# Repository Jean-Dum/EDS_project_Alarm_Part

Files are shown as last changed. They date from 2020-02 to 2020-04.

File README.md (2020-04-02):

# EDS_project_Alarm_Project

## Motion detection alarm

## Principal Equipment

	- PIR Sensor               --> EKMC1601111 - Motion sensor 5m 94°, Panasonic
	
	- Electromechanical Buzzer --> kmtg1603 

	- Button (For alarm test)  --> https://www.elfa.se/en/tactile-switch-pts-1no-160gf-6mm-pts645sm43smtr92lfs/p/30119498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

	- Variable resistor (for smoke sensor) --> https://www.elfa.se/en/trimmer-potentiometer-kohm-250-mw-bi-technologies-23br1klftr/p/16432066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
	
	- LoRa module (long range low-power wide-area network technology) --> Murata CMWX1ZZABZ

	- Smoke Sensor --> HS-131 https://www.elfa.se/en/gas-sensor-sencera-co-ltd-hs-131/p/17302706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

### Desired features

The main idea is to build a system which can detect the movement of a person using a PIR sensor. This movement will trigger an alarm and communicate using LoRa to another MCU managed by our associated team. The only way of desactivate the alarm is to introduce the correct code in the second team's terminal.

The system will also include a buzzer and a test button.

### Obtained features

Our PCB is now able to detect the movements up to 4 meters away. It makes the buzzer ring and to stop it you just have to press the button on the PCB.

At the programm beginning there is 10 seconds of waiting in order to wait for the user to go away (otherwise it will disrupt the sensor calibration) during which the info LED is blinking. Then there is 10 seconds of sensor calibration, in which it makes a 40 samples average to make a reference value and makes the LED blinking faster.

Then the programm runs and the buzzer will ring only if the sensor value exceeds the reference value.

If the alarm is stopped by pressing the button, to reactivate it just press again the buttton, the software will again wait 10 seconds to let the user go away to avoid the buzzer to ring immediatly and then run motion detection again. During this time the info LED is blinking again.

Our system send a '1' by serial connection when the sensor is triggered. The alarm can be turned off by serial connection if it receive a '1' but to do so you have to uncomment lines 143 to 152 and build the code again.

#### Here is a diagram of our program:
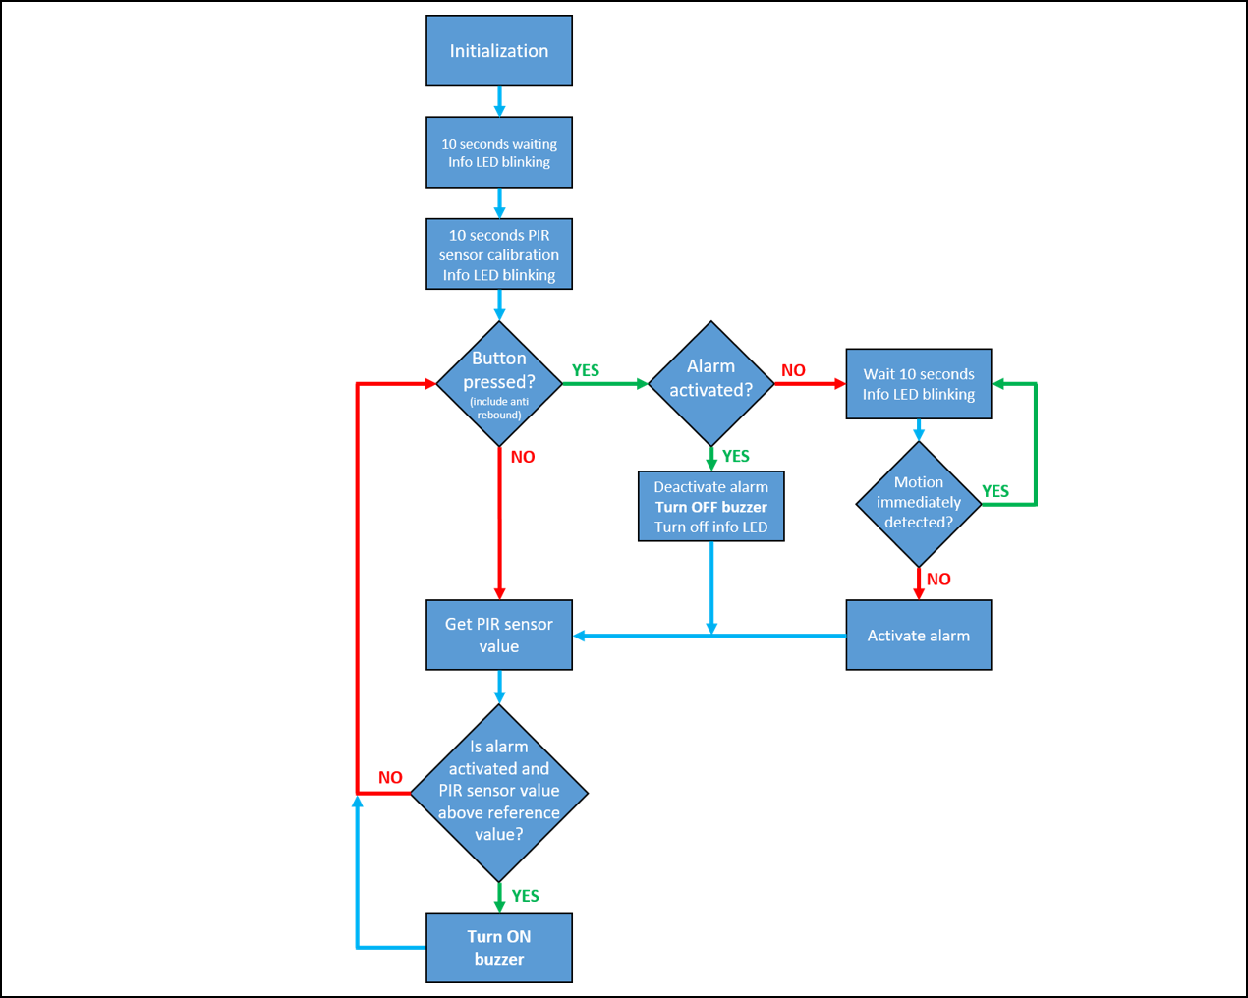
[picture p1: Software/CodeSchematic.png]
Code schematic description


## Run project

### Hardawre

- Connect the St-Link programmer from the nucleo board to the PCB. To do so just connect the SWD pins to the programming pins of our PCB, in the same order.
- Then verify that the nucleo St-Link programmer wont programm the nucleo board but our PCB. To do so remove the St-Link programmer and nucleo board connectors and remove the connector that power the nucleo board.
- Then connect both the St-Link programmer and PCB USB to your computer.

### Software
Open a terminal
#### Packages installation
- First of all install openocd:
> sudo apt-get install openocd
- install cargo:
> sudo apt-get install cargo
- install arm-none-eabi-gdb:
> sudo apt-get install arm-none-eabi-gdb
- Update rust tools:
> rustup update
> rustup target add thumbv7em-none-eabihf

#### Build software
> cargo build --release

#### Run software
- Clone this repo on your computer:
> git clone https://github.com/Jean-Dum/EDS_project_Alarm_Part.git
- Then go in the software directory:
> cd EDS_project_Alarm_Part/Software/
- Execute openocd software:
> openocd -f openocd.cfg
- Open a new terminal (in the same directory) and run the code:
> cargo build --release
- Now you are in the GDB interface, just type "c" and press two times enter key. You can look the code output in the openocd terminal.

## Possible Extras

If everything goes on time and we do not have any big difficulties in the project, we plan to add also some kind of smoke detector so the alarm system is more complete. 

We also thought of adding a fingerprint sensor for desactivating the alarm in the detector terminal.

## Limitations

The fact of working two groups together makes the communication between terminals harder but we dont expect any other big problem in our terminal.

The main limitation was that there few informations about Rust (and especially about the stm32L0) on internet, doing our researchs to resolve our problems was really difficult.

## Design and Electronic

We design our circuit using Kicad and testing some parts of the circuit in LTspice.  

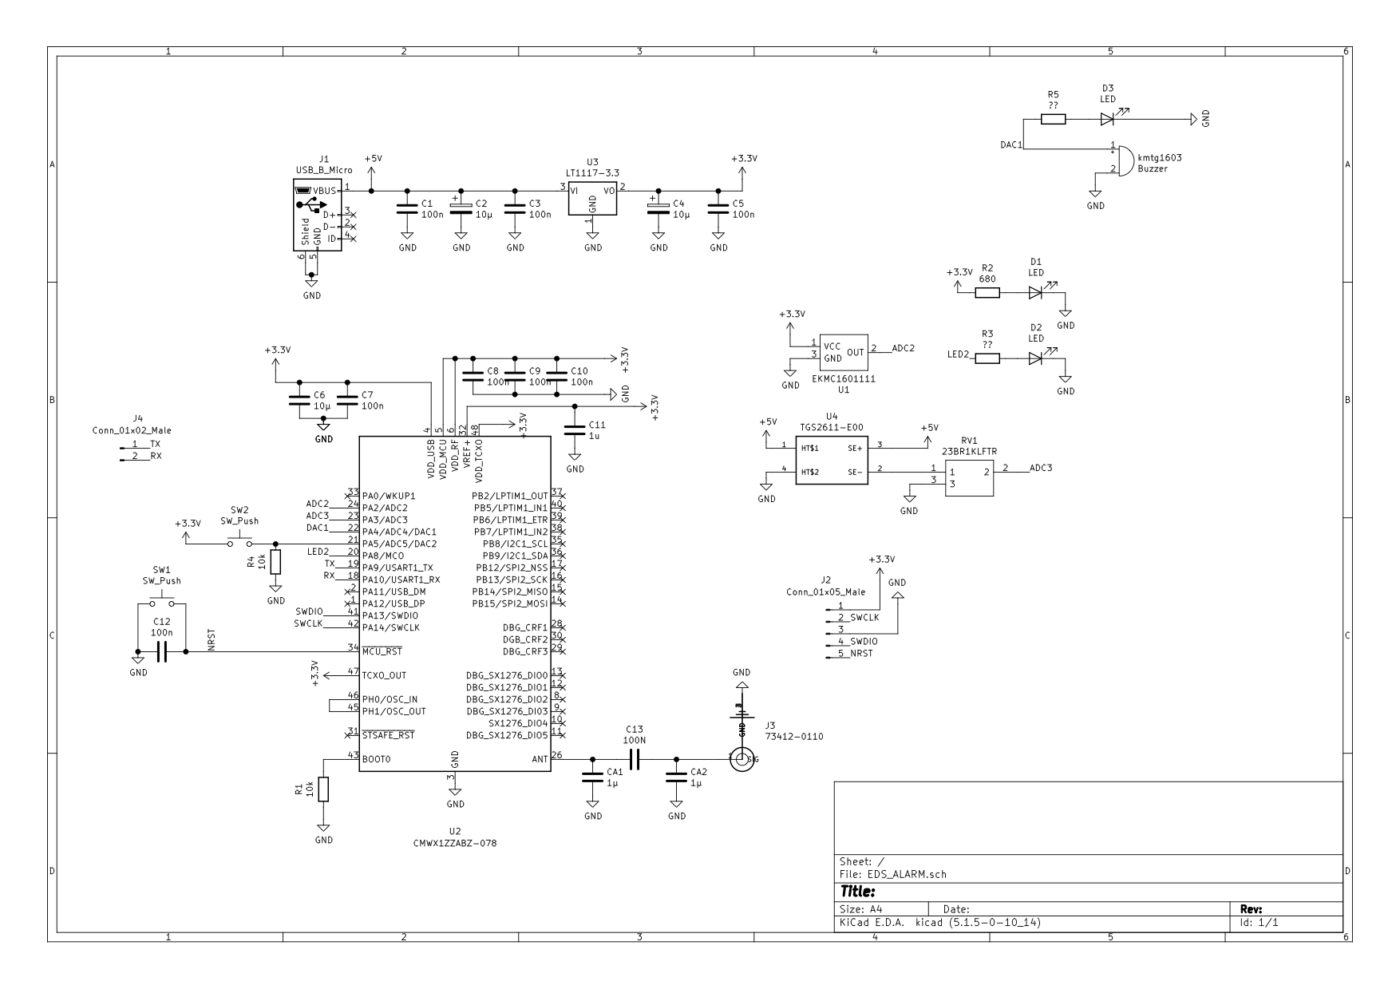
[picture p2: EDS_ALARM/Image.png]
Schematic
   

### Some facts about the circuit
	
- Three different LEDs: one to get infos on the code execution, one for the power and one connected to the buzzer.
	
- We add a different voltage regulator (LT1117) that allows us to have 3.3v always without the need of resistors for adjustment of the output, so we reduces the space used.

- For the Smoke detector we used a potentiometer we can use for changing the output, this is because the detector can work on different environments (humidity, temperature...) and we need to adjust the potentiometer to have an ideal output.

### Layout

For the layout we tried to make the PCB as small as possible so it can fit in a small case and this way the detection system will be more inconspicuous.

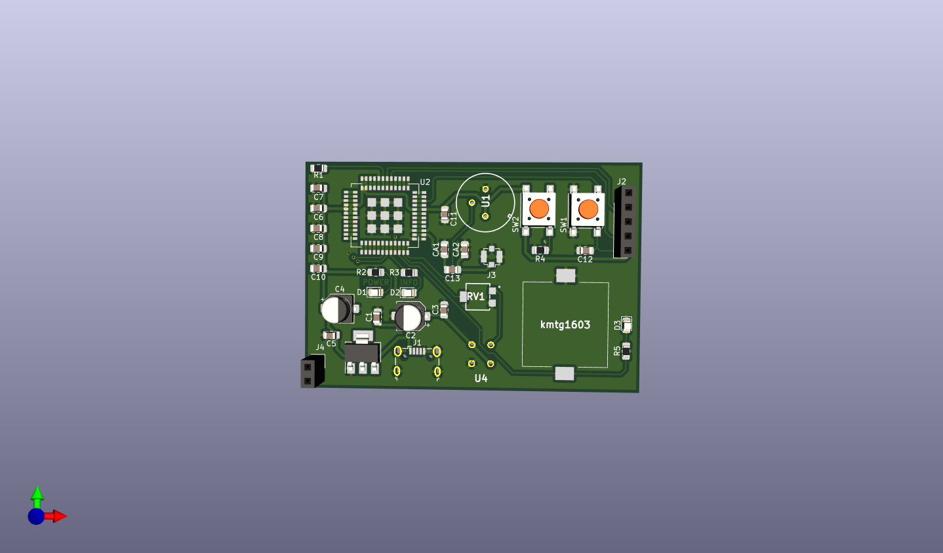
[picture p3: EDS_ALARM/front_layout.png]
Top Layout
   
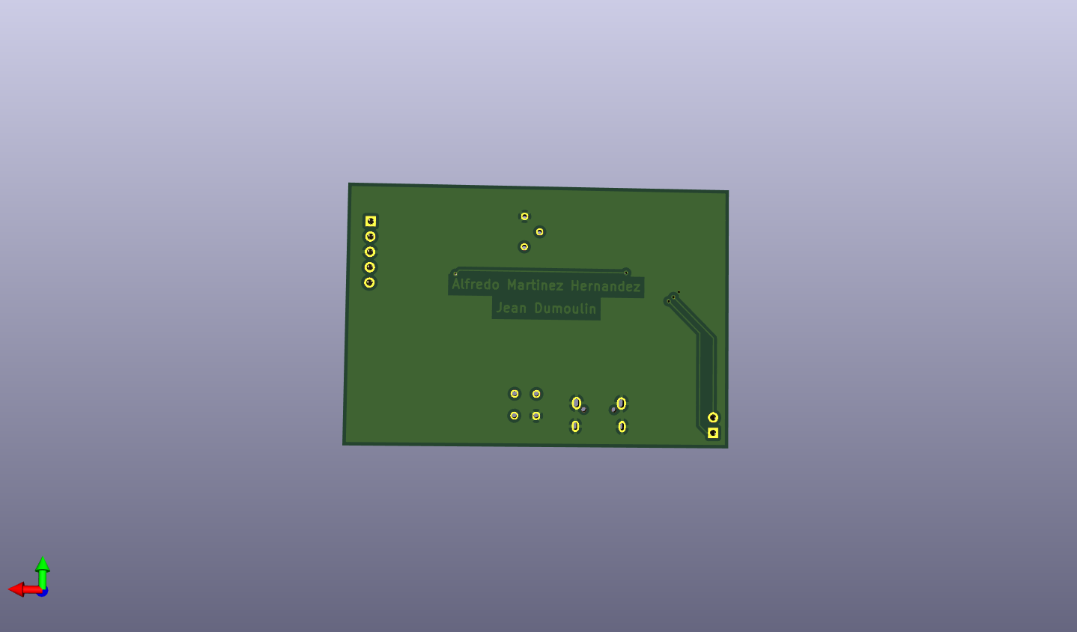
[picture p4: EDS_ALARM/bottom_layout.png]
Bottom Layout
   

All the components are on the same layer (top) but the PIR, this way we have more space and a better 'view' for the motion sensor. The connectors are all placed on the sides of the board so it is easier to use them. We tried to put the buzzer as far as possible from the MCU just incase the vibrations of the buzzer can make any damage on the small soldering pads of the MCU in a large period of time, the decoupling capacitors and sensors are placed as close as possible from the MCU.

### Testing

We did some different tests on the board before and after ordering it
- We used LTspice to make sure everything was okey
- Test for short-circuits and bad connections
- Test after soldering the MCU
- For short-circuits between pads (here we detected a problem)
- For voltage reverse to make sure all the pads were connected
- We tested the MCU by connecting it at a low current
- Test the final performance 

## Issues / Problems 

- Circuit
	- The LT1117 pins of the footprint where wrong (they were saved as if it was LM1117) so we had to make a small fix

- Layout and soldering
	- We had to apply the re-flow process twice because of a lack of flux in the first re-flow but finally applying more flux and doing the process again we managed to solder it perfect.

- Programming
	- It took us some time to manage to connect the PCB and didn't succeed to use vscode to run our code.
	- We made a mistake on the pins connection: The PA4 pin (used for the buzzer) don't generate PWM, we had to add a wire between the PA4 and PA3 pins because PA3 can generate PWM and is used for the smoke sensor, which is not used.
	- We didn't succeed to use the Lora module, by lack of time and because this one is way to complicated to use.
	- All the programming part was really complicated to realise, in fact there is not a lot of things about rust and espetially with the stm32L0 on internet, resolving our issues was a real struggle.

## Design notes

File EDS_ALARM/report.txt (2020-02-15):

Se ha creado el archivo de trazado "/Users/alfredomartinezhernandez/Documents/GitHub/PROJECTS/EDS_project_Alarm_Part/EDS_ALARM/EDS_ALARM-F_Cu.gbr".
Se ha creado el archivo de trazado "/Users/alfredomartinezhernandez/Documents/GitHub/PROJECTS/EDS_project_Alarm_Part/EDS_ALARM/EDS_ALARM-B_Cu.gbr".
Se ha creado el archivo de trazado "/Users/alfredomartinezhernandez/Documents/GitHub/PROJECTS/EDS_project_Alarm_Part/EDS_ALARM/EDS_ALARM-F_Adhes.gbr".
Se ha creado el archivo de trazado "/Users/alfredomartinezhernandez/Documents/GitHub/PROJECTS/EDS_project_Alarm_Part/EDS_ALARM/EDS_ALARM-B_Adhes.gbr".
Se ha creado el archivo de trazado "/Users/alfredomartinezhernandez/Documents/GitHub/PROJECTS/EDS_project_Alarm_Part/EDS_ALARM/EDS_ALARM-F_Paste.gbr".
Se ha creado el archivo de trazado "/Users/alfredomartinezhernandez/Documents/GitHub/PROJECTS/EDS_project_Alarm_Part/EDS_ALARM/EDS_ALARM-B_Paste.gbr".
Se ha creado el archivo de trazado "/Users/alfredomartinezhernandez/Documents/GitHub/PROJECTS/EDS_project_Alarm_Part/EDS_ALARM/EDS_ALARM-F_SilkS.gbr".
Se ha creado el archivo de trazado "/Users/alfredomartinezhernandez/Documents/GitHub/PROJECTS/EDS_project_Alarm_Part/EDS_ALARM/EDS_ALARM-B_SilkS.gbr".
Se ha creado el archivo de trazado "/Users/alfredomartinezhernandez/Documents/GitHub/PROJECTS/EDS_project_Alarm_Part/EDS_ALARM/EDS_ALARM-F_Mask.gbr".
Se ha creado el archivo de trazado "/Users/alfredomartinezhernandez/Documents/GitHub/PROJECTS/EDS_project_Alarm_Part/EDS_ALARM/EDS_ALARM-B_Mask.gbr".
Se ha creado el archivo de trazado "/Users/alfredomartinezhernandez/Documents/GitHub/PROJECTS/EDS_project_Alarm_Part/EDS_ALARM/EDS_ALARM-Edge_Cuts.gbr".
Se ha creado el archivo de trazado "/Users/alfredomartinezhernandez/Documents/GitHub/PROJECTS/EDS_project_Alarm_Part/EDS_ALARM/EDS_ALARM-Margin.gbr".
Se ha creado el archivo de trazado "/Users/alfredomartinezhernandez/Documents/GitHub/PROJECTS/EDS_project_Alarm_Part/EDS_ALARM/EDS_ALARM-F_CrtYd.gbr".
Se ha creado el archivo de trazado "/Users/alfredomartinezhernandez/Documents/GitHub/PROJECTS/EDS_project_Alarm_Part/EDS_ALARM/EDS_ALARM-B_CrtYd.gbr".
Se ha creado el archivo de trazado "/Users/alfredomartinezhernandez/Documents/GitHub/PROJECTS/EDS_project_Alarm_Part/EDS_ALARM/EDS_ALARM-F_Fab.gbr".
Se ha creado el archivo de trazado "/Users/alfredomartinezhernandez/Documents/GitHub/PROJECTS/EDS_project_Alarm_Part/EDS_ALARM/EDS_ALARM-B_Fab.gbr".

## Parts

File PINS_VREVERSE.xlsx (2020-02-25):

pin Nº | DESCRIPTION | V(reverse)
1 | X | 0.702
2 | X | 0.697
3 | GND | 0.001
4 | VDD_USB | 0.948
5 | VDD_MCU | 0.948
6 | VDD_RF | 0.948
7 | GND | 0.001
8 | X | 1383
9 | X | 0.986
10 | X | 1383
11 | X | 1384
12 | X | 1386
13 | X | 0.680
14 | X | 0.741
15 | X | 0.711
16 | X | 0.710
17 | X | 0.734
18 | RX | 0.706
19 | TX | 0.711
20 | LED2 | 0.714
21 | PA5(SWITCH) | 0.686
22 | DAC1(BUZZER) | 0.687
23 | ADC3(SMOKE) | 0.720
24 | ADC2 (PIR) | 0.721
25 | GND | 0.001
26 | ANTENA | ??
27 | GND | 0.001
28 | X | 0.721
29 | X | 0.707
30 | X | 0.707
31 | X | ??
32 | VREF+ | 0.403
33 | X | 0.720
34 | NRST | 0.739
35 | X | 0.713
36 | X | 0.716
37 | X | ??
38 | X | ??
39 | X | ??
40 | X | ??
41 | SWDIO | 0.739
42 | SWCLK | 0.739
43 | BOOT0 | 0.731
44 | GND | 0.001
45 | OSC_OUT | 0.691
46 | OSC_IN | 0.690
47 | TCXO_OUT | 0.403
48 | VDD_TCX0 | 0.403
49 | GND
50 | GND
51 | GND
52 | GND
53 | GND
54 | GND
55 | GND
56 | GND
57 | GND

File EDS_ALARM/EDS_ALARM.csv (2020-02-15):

Id | Identificador | Empaquetado | Cantidad | Identificación | Suministrador y ref
1 | R2 | R_0805_2012Metric_Pad1.15x1.40mm_HandSolder | 1 | 680 |  | x
2 | U2 | CMWX1ZZABZ_NEW | 1 | CMWX1ZZABZ-078
3 | C1,C3,C5,C7,C8,C9,C10,C12 | C_0805_2012Metric_Pad1.15x1.40mm_HandSolder | 8 | 100n |  | x
4 | C2,C4 | CP_Elec_5x4.4 | 2 | 10µ |  | x
5 | C6 | C_0805_2012Metric_Pad1.15x1.40mm_HandSolder | 1 | 10µ |  | x
6 | C11 | C_0805_2012Metric_Pad1.15x1.40mm_HandSolder | 1 | 1u |  | x
7 | C13 | C_0805_2012Metric_Pad1.15x1.40mm_HandSolder | 1 | 100N |  | x
8 | CA1,CA2 | C_0805_2012Metric_Pad1.15x1.40mm_HandSolder | 2 | 1µ |  | x
9 | J1 | USB_Mini-B_Lumberg_2486_01_Horizontal CHANGED!! | 1 | USB_B_Micro |  | X
10 | J3 | U.FL_Molex_MCRF_73412-0110_Vertical | 1 | 73412-0110 |  | X
11 | R1,R4 | R_0805_2012Metric_Pad1.15x1.40mm_HandSolder | 2 | 10k |  | X
12 | U3 | SOT-223 | 1 | LT1117-3.3 |  | X
13 | U1 | VZ-STANDARD | 1 | EKMC1601111 |  | X
14 | D1,D2,D3 | LED_0805_2012Metric | 3 | LED |  | X
15 | RV1 | 23B_1 | 1 | 23BR1KLFTR |  | X
16 | SW1,SW2 | SW_SPST_PTS645 | 2 | SW_Push |  | X
17 | kmtg1603 | KMTG16031 | 1 | Buzzer |  | X
18 | U4 | TGS2611C00 | 1 | TGS2611-E00 |  | X
19 | J2 | PinSocket_1x05_P2.54mm_Vertical | 1 | Conn_01x05_Male |  | x
20 | J4 | PinSocket_1x02_P2.54mm_Vertical | 1 | Conn_01x02_Male |  | X
21 | R3,R5 | R_0805_2012Metric_Pad1.15x1.40mm_HandSolder | 2 | ?? |  | x

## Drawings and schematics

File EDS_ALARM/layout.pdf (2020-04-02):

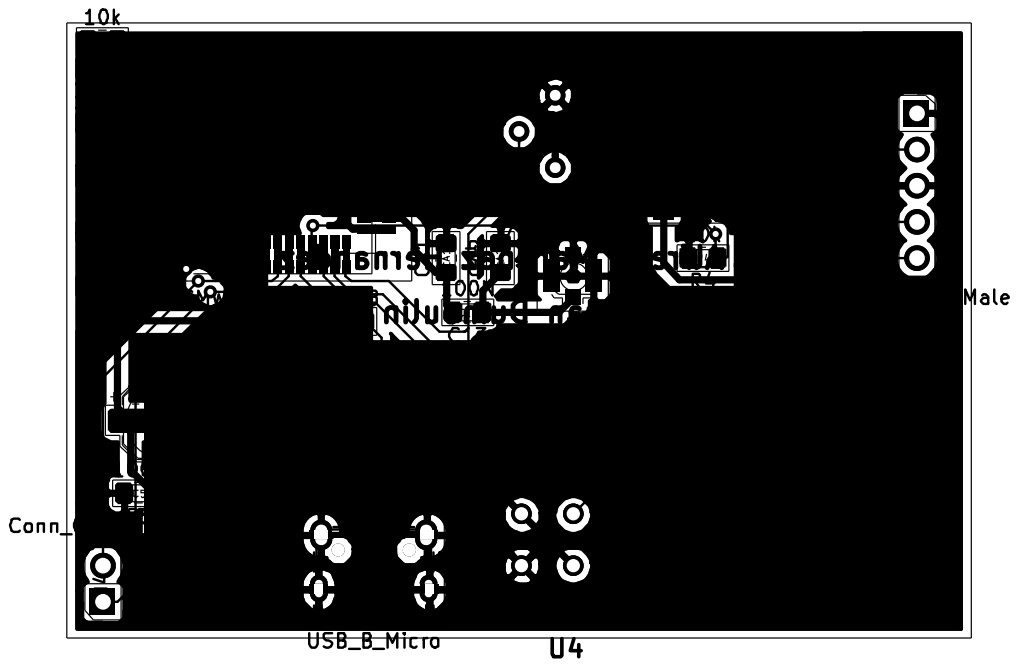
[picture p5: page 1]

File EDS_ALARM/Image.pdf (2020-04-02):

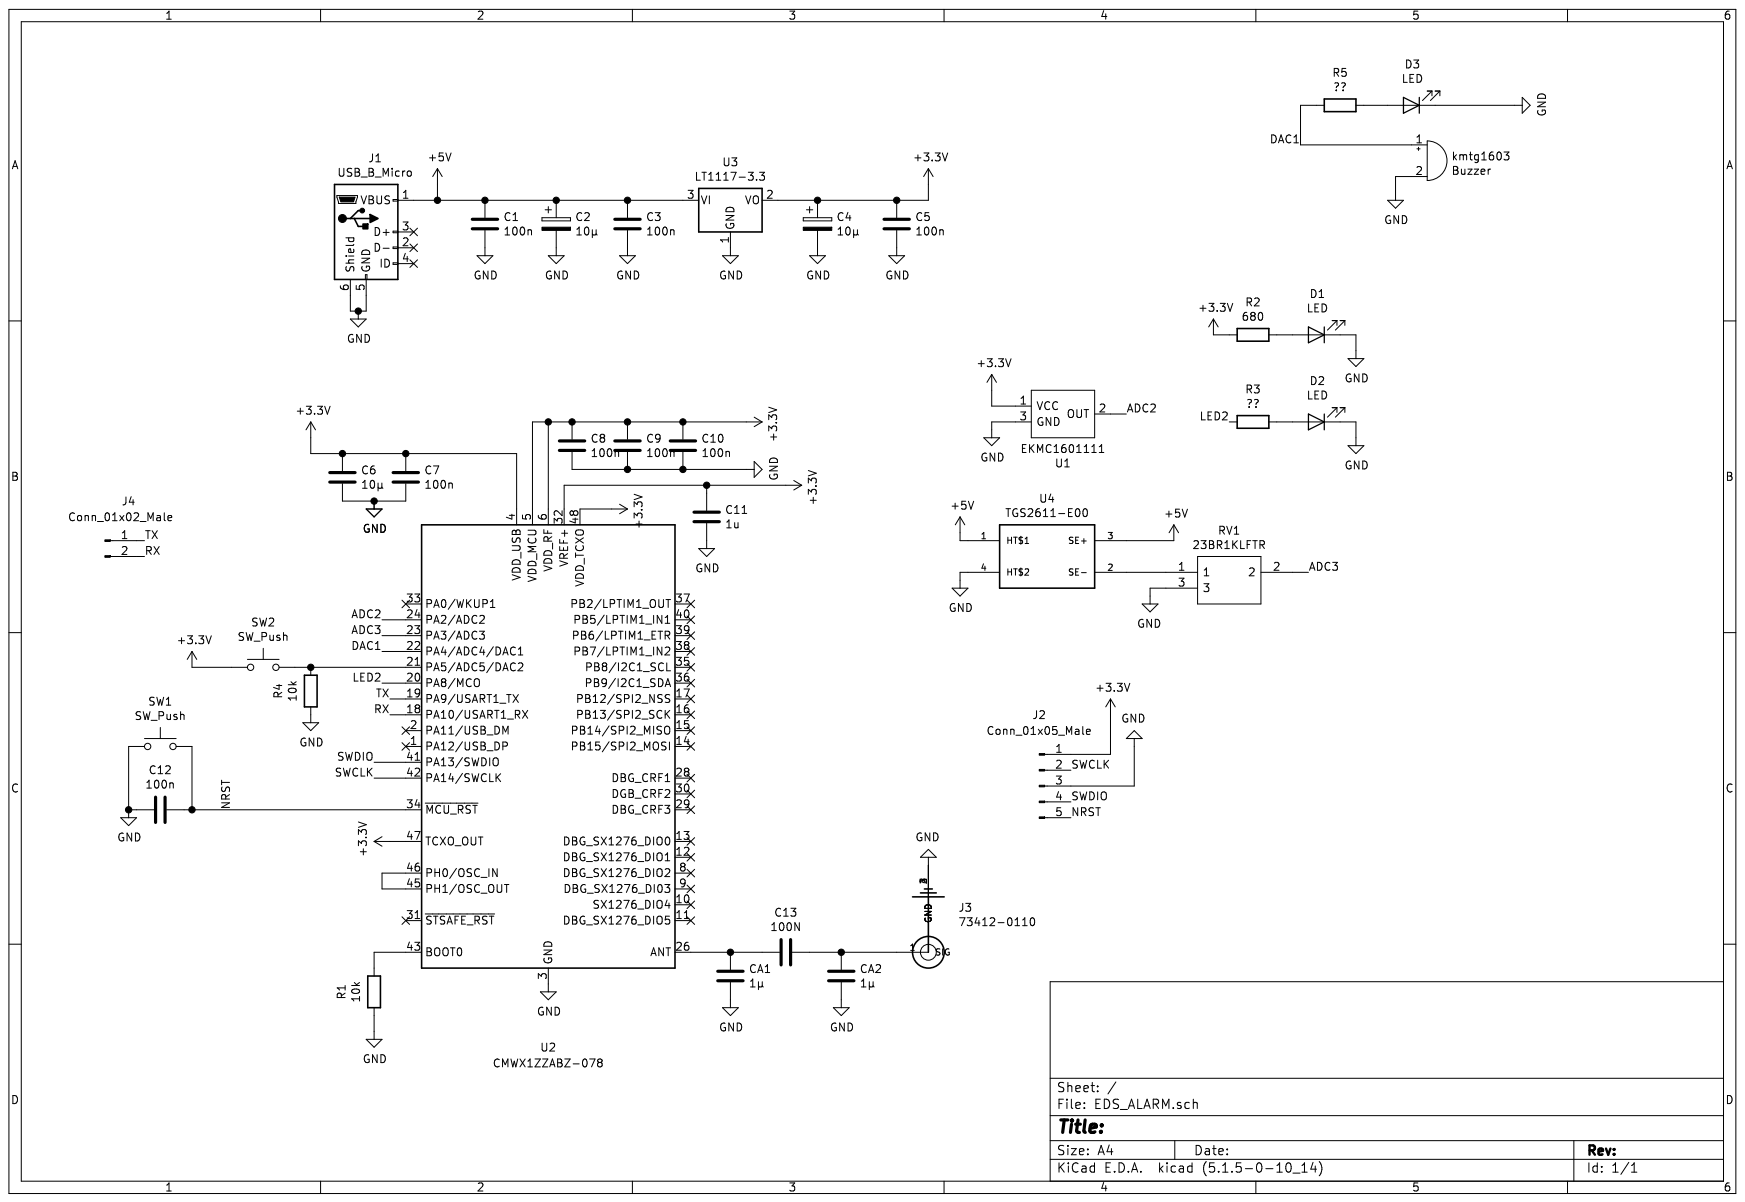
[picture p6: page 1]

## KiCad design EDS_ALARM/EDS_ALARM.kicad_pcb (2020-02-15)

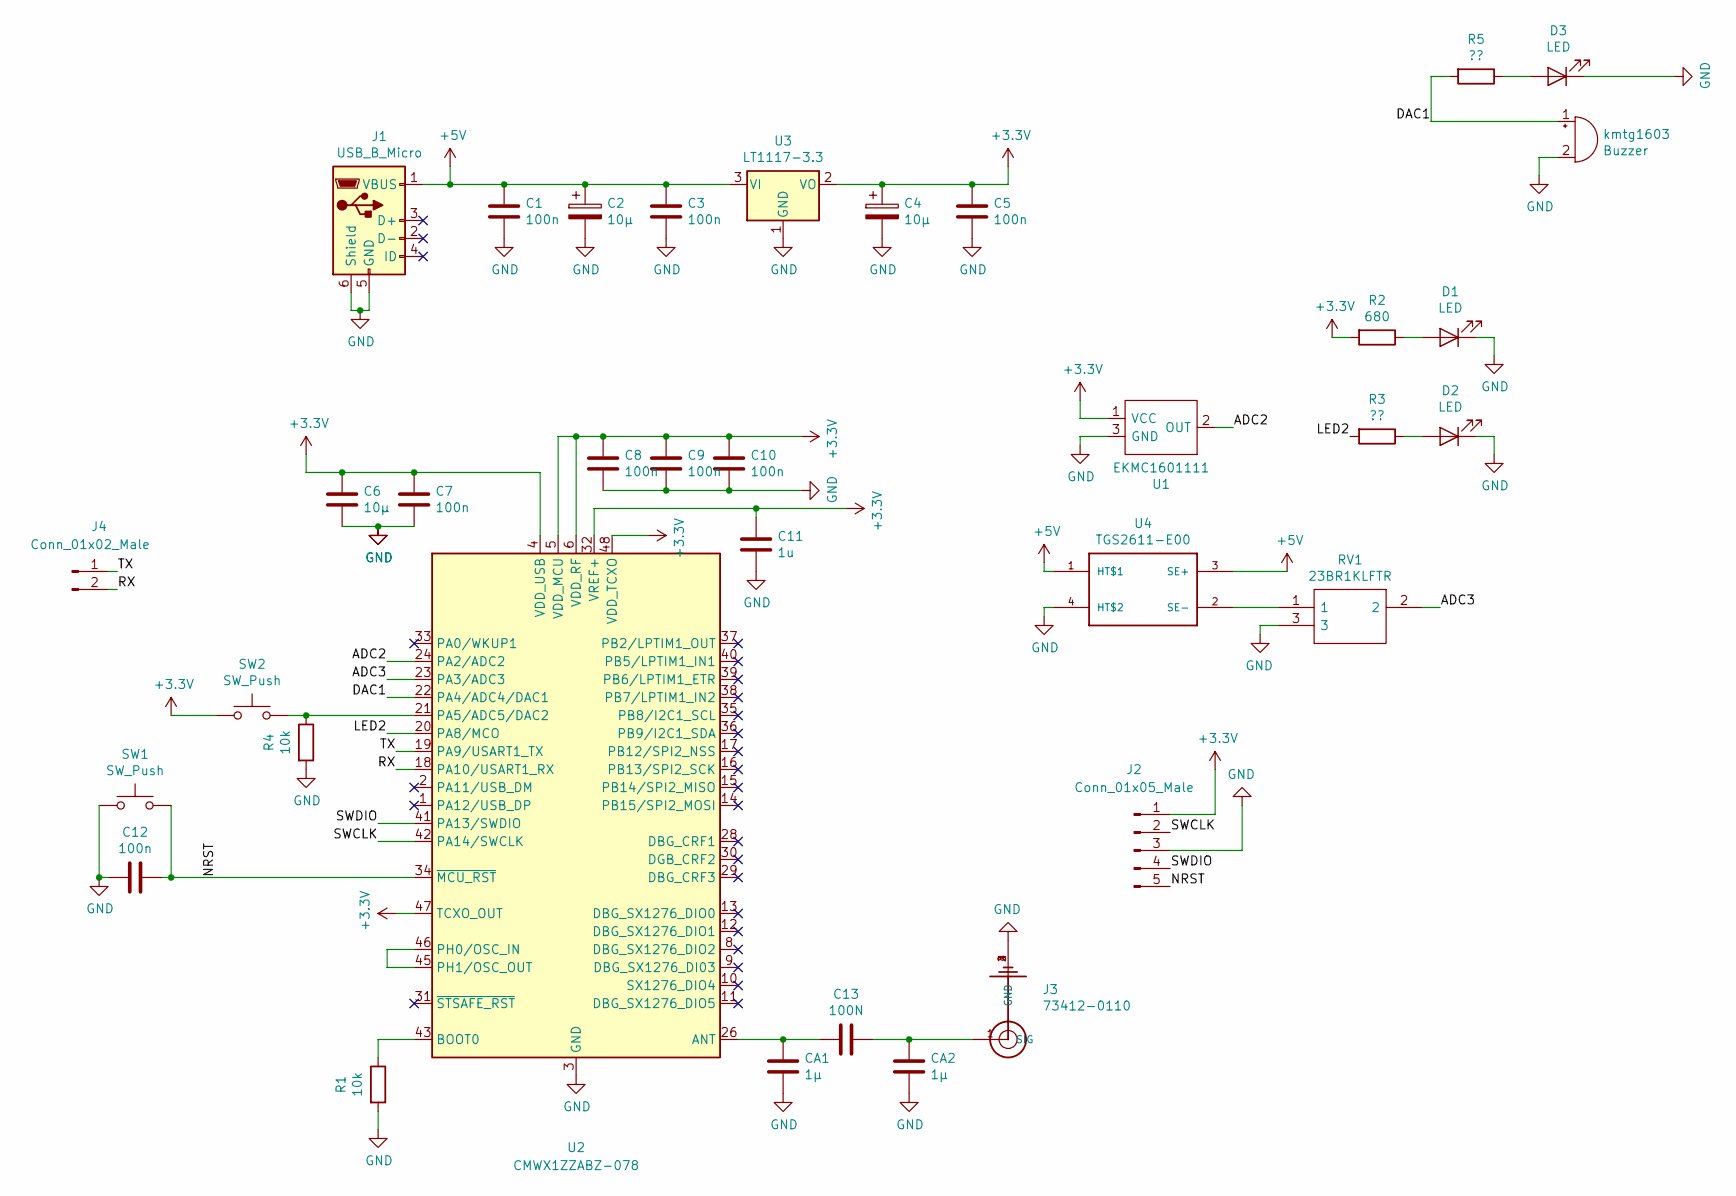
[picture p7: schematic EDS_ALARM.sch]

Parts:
C1, C3, C5, C7, C8, C9, C10, C12: 100n; C_0805_2012Metric_Pad1.15x1.40mm_HandSolder
C2, C4: 10µ; CP_Elec_5x4.4
C6: 10µ; C_0805_2012Metric_Pad1.15x1.40mm_HandSolder
C11: 1u; C_0805_2012Metric_Pad1.15x1.40mm_HandSolder
C13: 100N; C_0805_2012Metric_Pad1.15x1.40mm_HandSolder
CA1, CA2: 1µ; C_0805_2012Metric_Pad1.15x1.40mm_HandSolder
D1, D2, D3: LED; LED_0805_2012Metric
J1: USB_B_Micro; USB_Micro-B_Wuerth_629105150521
J2: Conn_01x05_Male; PinSocket_1x05_P2.54mm_Vertical
J3: 73412-0110; U.FL_Molex_MCRF_73412-0110_Vertical
J4: Conn_01x02_Male; PinSocket_1x02_P2.54mm_Vertical
R1, R4: 10k; R_0805_2012Metric_Pad1.15x1.40mm_HandSolder
R2: 680; R_0805_2012Metric_Pad1.15x1.40mm_HandSolder
R3, R5: ??; R_0805_2012Metric_Pad1.15x1.40mm_HandSolder
RV1: 23BR1KLFTR; 23B_1; Manufacturer_Part_Number 23BR1KLFTR; Mouser Part Number 858-23BR1KLFTR
SW1, SW2: SW_Push; SW_SPST_PTS645
U1: EKMC1601111; VZ-STANDARD; Manufacturer_Part_Number EKMC1601111; Mouser Part Number 769-EKMC1601111
U2: CMWX1ZZABZ-078; CMWX1ZZABZ_NEW
U3: LT1117-3.3; SOT-223
U4: TGS2611-E00; TGS2611C00
kmtg1603: Buzzer; KMTG16031

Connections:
+3V3: C4.1, C5.1, C6.1, C7.1, C8.1, C9.1, C10.1, C11.1, J2.1, R2.2, SW2.1, U1.1 (VCC), U2.4 (VDD_USB), U2.5 (VDD_MCU), U2.6 (VDD_RF), U2.32 (VREF+), U2.47 (TCXO_OUT), U2.48 (VDD_TCXO), U3.2 (VO)
+5V: C1.1, C2.1, C3.1, J1.1 (VBUS), U3.3 (VI), U4.1 (HT$1), U4.3 (SE+)
/ADC2: U1.2 (OUT), U2.24 (PA2/ADC2)
/ADC3: RV1.2, U2.23 (PA3/ADC3)
/DAC1: R5.2, U2.22 (PA4/ADC4/DAC1), kmtg1603.1 (-)
/LED2: R3.2, U2.20 (PA8/MCO)
/NRST: C12.1, J2.5, SW1.2, U2.34 (~MCU_RST)
/RX: J4.2, U2.18 (PA10/USART1_RX)
/SWCLK: J2.2, U2.42 (PA14/SWCLK)
/SWDIO: J2.4, U2.41 (PA13/SWDIO)
/TX: J4.1, U2.19 (PA9/USART1_TX)
GND: C1.2, C2.2, C3.2, C4.2, C5.2, C6.2, C7.2, C8.2, C9.2, C10.2, C11.2, C12.2, CA1.2, CA2.2, D1.1 (K), D2.1 (K), D3.1 (K), J1.5 (GND), J1.6 (Shield), J2.3, J3.2 (GND), J3.3 (GND), J3.4 (GND), R1.2, R4.2, RV1.3, SW1.1, U1.3 (GND), U2.3 (GND), U2.7 (GND), U2.25 (GND), U2.27 (GND), U2.44 (GND), U2.49 (GND), U2.50 (GND), U2.51 (GND), U2.52 (GND), U2.53 (GND), U2.54 (GND), U2.55 (GND), U2.56 (GND), U2.57 (GND), U3.1 (GND), U4.4 (HT$2), kmtg1603.2 (+)
unnamed: C13.1, CA2.1, J3.1 (SIG)
unnamed: C13.2, CA1.1, U2.26 (ANT)
unnamed: D1.2 (A), R2.1
unnamed: D2.2 (A), R3.1
unnamed: D3.2 (A), R5.1
unnamed: R1.1, U2.43 (BOOT0)
unnamed: R4.1, SW2.2, U2.21 (PA5/ADC5/DAC2)
unnamed: RV1.1, U4.2 (SE-)
unnamed: U2.45 (PH1/OSC_OUT), U2.46 (PH0/OSC_IN)

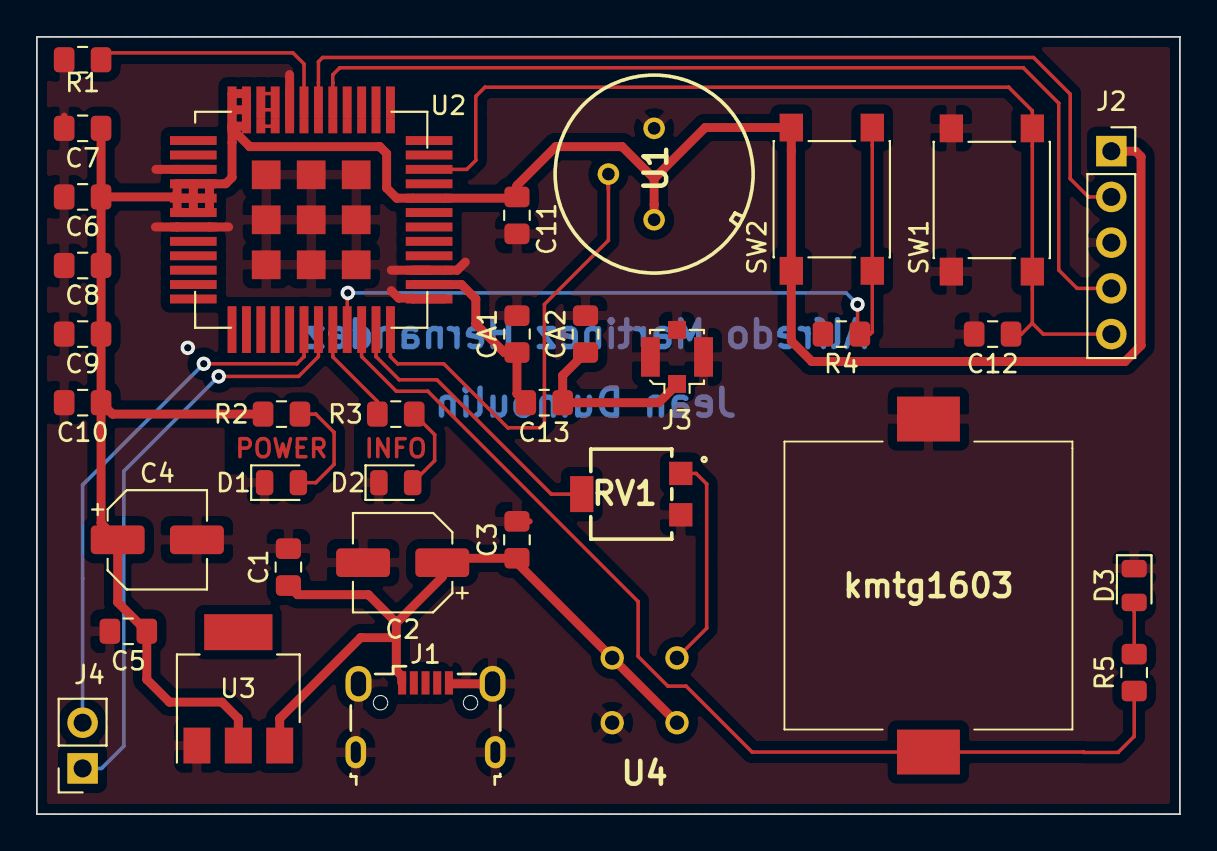
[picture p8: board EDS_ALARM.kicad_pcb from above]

Board: 2 copper layers, 63.5 x 43.2 mm, 35 parts (0 on the bottom side), 21 nets.

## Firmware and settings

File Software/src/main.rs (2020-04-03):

// Made by Jean Dumoulin and Alfredo Martinez Hernandez
// This code is meant to ring the alarm when the PIR sensor detects movement next to it

#![no_main]
#![no_std]
#![allow(non_snake_case)] 
#![deny(unsafe_code)]
#![deny(warnings)]

extern crate panic_halt;

use cortex_m_rt::entry;
use cortex_m_semihosting::{hprintln, hprint};
use stm32l0xx_hal::{self, pac, pwm, prelude::*, rcc::Config, serial};
// use nb::block; Uncomment if serial input is used

extern crate cortex_m;

#[entry]
fn main() -> ! {
    hprintln!("\nBeginning initialization").unwrap();

    let dp = pac::Peripherals::take().unwrap();
    let cp = cortex_m::Peripherals::take().unwrap();

    // Configure the clock.
    let mut rcc = dp.RCC.freeze(Config::hsi16());

    // Get the delay provider.
    let mut delay = cp.SYST.delay(rcc.clocks);

    // Acquire the GPIOA peripheral. This also enables the clock for GPIOA in the RCC register.
    let gpioa = dp.GPIOA.split(&mut rcc);

    // Configure PA8 as output (info LED output)
    let mut infoLED = gpioa.pa8.into_push_pull_output();

    // Configure PA5 as input (SW2)
    let button = gpioa.pa5.into_push_pull_output();
    
    // Configure the timer as PWM on PA3 (connected to PA4)
    let pwm = pwm::Timer::new(dp.TIM2, 1.khz(), &mut rcc);
    let mut pwm = pwm.channel4.assign(gpioa.pa3);
    let max_duty = pwm.get_max_duty() / 4095;
    pwm.enable();
    
    // Configure ADC on PA2
    let mut adc = dp.ADC.constrain(&mut rcc);
    let mut a2 = gpioa.pa2.into_analog();

    // Configure the serial peripheral on pa9 and pa10
    let tx_pin = gpioa.pa9;
    let rx_pin = gpioa.pa10;
    let serial = dp
        .USART1
        .usart((tx_pin, rx_pin), serial::Config::default(), &mut rcc)
        .unwrap();
    let (mut tx, _rx) = serial.split();

    // Initialize PIR reference value to 0
    let mut PIR_ref:u16 = 0;

    // Initialize the alarm activation boolean
    let mut alarmOnOff = true;

    // 5 seconds pause, indicates to the user that he must move away to avoid an immediate ringing
    for x in 0..10 {
        hprint!("\rWait {}s", 4 - x/2).unwrap();
        // Blink the info LED: 250ms OFF, 250ms ON
        delay.delay(250.ms());
        infoLED.set_low().unwrap();
        delay.delay(250.ms());
        infoLED.set_high().unwrap();
    }
    // Print new line
    hprintln!("").unwrap();
    // 5 seconds initialization time, makes the sum of 20 samples
    for x in 0..20 {
        hprint!("\rCalibration: {}s", 4 - x/4).unwrap();
        // Sum a PIR ADC sample
        PIR_ref = PIR_ref.wrapping_add(adc.read(&mut a2).unwrap());
        // Blink the info LED: 125ms OFF, 125ms ON
        delay.delay(125.ms());
        infoLED.set_low().unwrap();
        delay.delay(125.ms());
        infoLED.set_high().unwrap();
    }

    // Divide the result of the sum by 20, the result of the average is doubled
    let PIR_ref: u16 = PIR_ref/10;
    // Prints the average result
    hprintln!("\nReference value: {}\n", PIR_ref).unwrap();

    loop {
        // If the button is pushed
        if button.is_high().unwrap(){
            // Wait until the button is released
            while button.is_high().unwrap(){ 
                // Wait 200ms to avoid rebounce
                delay.delay(200.ms());
            }
            // Invert the alarm switch
            alarmOnOff = !alarmOnOff;
            // If the alarm is activated
            if alarmOnOff == true{
                hprintln!("\nAlarm activated").unwrap();
                // 5 seconds pause, indicates to the user that he must move away, if not it continues
                let mut temp: u8 = 0;
                loop {
                    hprint!("\rWait {}s", 9 - temp/2).unwrap();
                    // Incremet of 500ms
                    temp += 1;
                    // Blink the info LED: 250ms OFF, 250ms ON
                    delay.delay(250.ms());
                    infoLED.set_low().unwrap();
                    delay.delay(250.ms());
                    infoLED.set_high().unwrap();
                    // Take a PIR ADC sample
                    let val: u16 = adc.read(&mut a2).unwrap();
                    // If 10 seconds passed and the PIR value is less than the reference, quit the loop
                    if temp >= 20 && val < PIR_ref  {
                        break();
                    }
                    // If 10 seconds passed and the PIR value is higher than the reference, wait 5 more seconds
                    else if temp >= 20{
                        temp = 0;
                    }
                }
                hprint!("\n").unwrap();
            }
            // If the alarm is desactivated
            else {
                tx.write(0).unwrap();
                hprintln!("\nAlarm desactivated").unwrap();
                // Turn OFF the info LED
                infoLED.set_low().unwrap();
                // Set the PWM duty cycle to 0
                pwm.set_duty(max_duty * 0);
            }
        }

        // Part of the code which allows to desactivate the alarm if a '1' is received on serial port
        /*
        if block!(rx.read()).unwrap() == 1 {
            tx.write(0).unwrap();
                hprintln!("\nAlarm desactivated").unwrap();
                // Turn OFF the info LED
                infoLED.set_low().unwrap();
                // Set the PWM duty cycle to 0
                pwm.set_duty(max_duty * 0);
        }
        */

        // Get the sensor value and print it
        let val: u16 = adc.read(&mut a2).unwrap();
        hprintln!("Val:{}", val).unwrap();

        // If the alarm is activated and the PIR sensor value is higher than the reference
        if val > PIR_ref && alarmOnOff == true{
            // Set the PWM duty cycle to 2000
            pwm.set_duty(max_duty * 2000);
            hprintln!("Alarm ON").unwrap();
            // Send it on I2C
            tx.write(1).unwrap();
        }
    }
}

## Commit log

2020-01-31 Adding Kicad harware empty files
    [EDS_Kicad.kicad_pcb, EDS_Kicad.sch]
2020-02-04 Adding PIR sensor symbol and footprint
    [EDS_ALARM.kicad_pcb, EDS_ALARM.sch]
2020-02-10 Adding correct footprints to corresponding symbols, adding cristal
    [EDS_ALARM.kicad_pcb, EDS_ALARM.sch]
2020-02-11 Finishing schematic
    [EDS_ALARM.sch]
2020-02-11 Finished layout
    [EDS_ALARM.kicad_pcb, EDS_ALARM.sch]
2020-02-11 Last layout modifications
    [EDS_ALARM.kicad_pcb]
2020-02-12 Layout improve
    [EDS_ALARM.kicad_pcb]
2020-02-12 Adding button, buzzer's LED
    [EDS_ALARM.kicad_pcb]
2020-02-13 MCU footprint updating
    [EDS_ALARM.kicad_pcb]
2020-03-09 Adding software directory
    [stm32f4x.cfg, stm32l0.cfg]
2020-03-09 Updating radio module code
    [stm32f4x.cfg]
2020-03-13 resolving some openocd issues
    [stlink-v2-1.cfg]
2020-03-20 working code: button, pwm, LED, ADC
2020-04-02 Resolving last issues, adding serial possibility
    [main.rs]
